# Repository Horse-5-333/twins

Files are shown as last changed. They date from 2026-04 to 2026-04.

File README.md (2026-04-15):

# Hourglass Twins Keyboard
### in 2021, [9% of Americans](https://doi.org/10.15620/cdc:129848) (~30 million people) experienced a repetitive strain injury
Constant typing in an office setting was found to be a significant risk factor. A key reason why is the keyboards many officeworkers use - the standard 104 key ANSI layout was not designed with people in mind. This project aims to implement strategic, ergonomic design choices that improve comfort during typing and decrease the risk of repetitive strain injury.
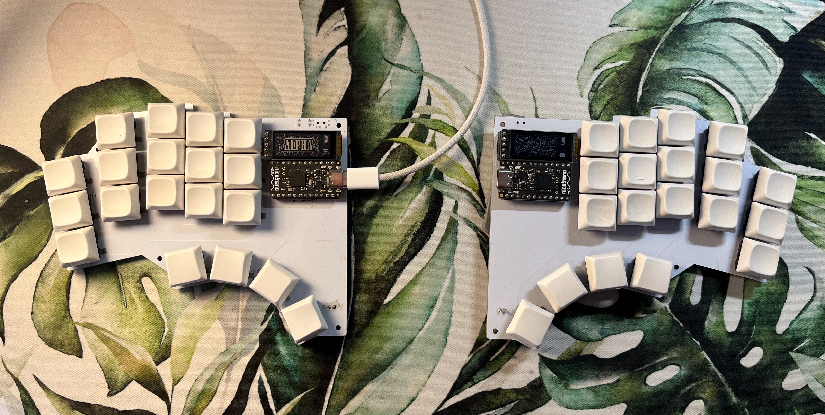
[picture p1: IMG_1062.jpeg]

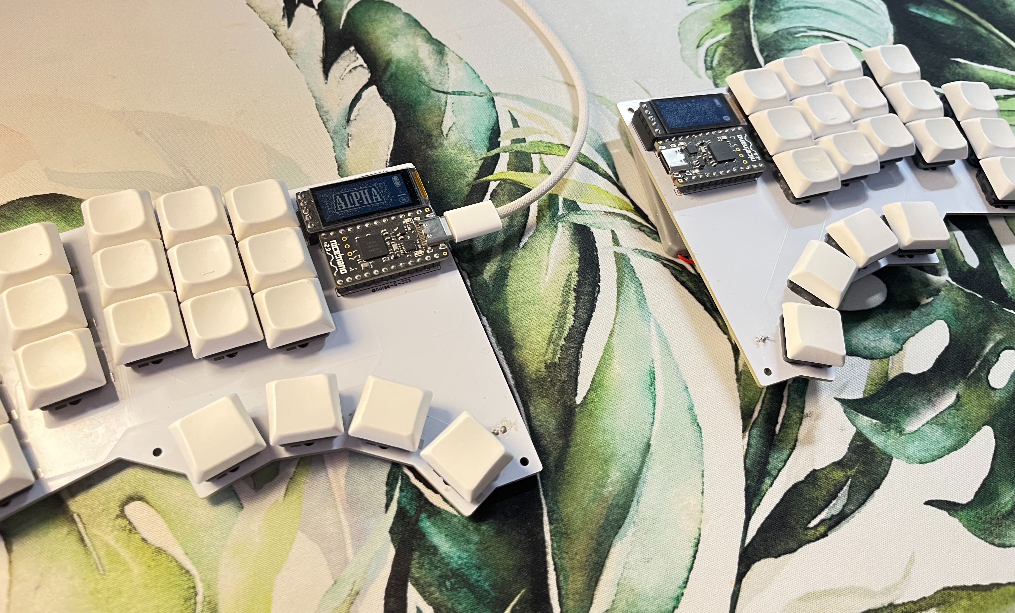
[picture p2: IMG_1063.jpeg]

## Ergonomics
The Hourglass Twins Keyboard implments, among others, 3 key design choices - a column (rather than the standard row) stagger, a thumb cluster, and angled offsets measured specifically to the average male hand size. However, this design is not without compromise; the slim layout would be a dealbreaker for many, as this keyboard only has 38 keys (though through the use of layers, there are actually 38x3=114 effective keys). The main goal of the keyboard is to unite the design and layout of the keys to the physical shape of the human hand, in positions that are comfortable to hold.

A key design goal of this keyboard was that no finger should have to move more than 1 key away to access the keys assigned to it. This, combined with the limted range of motion of the pink restricts the four main fingers to only 15 keys (the index finger gets 2 dedicated columns). The thumbs of each hand get 4 keys because it can swing wide, leading to an overall design of 19 keys per hand, or 38 total.
### Column Stagger
Typical keyboards have their rows offset from eachother. Some claim this is a vestige of typewriter design, but that source is not entirely accurate. This project uses a column stagger, where columns have different heights. This is because our finger lengths naturally vary, and it doesn't make sense to place the home row for the pinky at the same level for the middle finger.
### Angled Column Offset
Try extending your hand from a fist to palm-flat - notice how your fingers _aren't_ parallel? Even many ergonomic keyboards like to assume they are, but this one doesn't. The pinky and ring finger columns both angle away from the central cluster because that's how those fingers look on a hand. Pressing a top key with the pinky is far more comfortable if it just has to extend along its own axis.
### Thumb Cluster
The ANSI layout reserves almost 20% of the hand's fingers for one key: the spacebar. The thumb rarely presses  anything else on a standard keyboard. So, this keyboard utilizes the thumbs extensive range of motion with a comfortable thumb cluster positioned at the center of the board.

## Design
### Layers
Though noted in the paper that Dvorak should be used, further research into the topic reveals there are significantly more advancements to be made. This repo can be forked and the config file edited to match a more standard layout if desired.

The current layer is noted on the e-ink display on the left-half board.
| Layer | Access Key |  Mode | Details |
| -- | -- | -- | -- |
| Alpha | None | Default | Currently using a modified version of the [Caster Layout](https://cyanophage.github.io/#caster). |
| Symbol | Leftmost thumbkey of right-cluster | Hold | Alpha keys are overwritten with symbols such as !@#$%^&*() |
| Number | Rightmost thumbkey of left-cluster | Hold | Alpha keys are overwritten with a numpad on the right board and nav keys on the left board |
| QWERTY (game) | Symbol + Number layer keys at the same time| Toggle | Contains a QWERTY mode on the left-half, with an arragement o `F` keys on the right half. The configuration layer can be accessed from here |
| Config | Rightmost thumbkey of right-cluster while in QWERTY layer | Toggle | This layer contains keys that can control the Bluetooth connections of the board, and reset the board entirely |

### PCB Creation
Initially, I started with a design that I fine-tuned to match my hand from [ergogen](https://ergogen.cache.works/), a website specifically created to help improve the process of creating an ergonomic keyboard. I wrote a YAML configuration file, including PCB schematics and 3d printable bases, and exported it for use in KiCad and Fusion360. From there, I iterated over the design in KiCad, routing the hotswap sockets ergogen placed in the file to a microcontroller footprint on the main board. However, after ordering through JLCPCB, I learned there was a routing error in the drill file - a path overlapped a hotswap footprint where it should not, making a key that thought it was _always depressed_. This forced me to be more careful with my DRC before printing, though I am surprised I didn't catch this.

### Choosing a Layout
Initially, I was going to use Dvorak because it was the name that had popped up most in the academic research space on keyboard layouts. However, beyond that, in the online space, people have take what Dvorak has done and applied further optimization of keyboard layouts. As I had already decided this keyboard would use a custom layout which would require a strict learning curve anyways, I decided to go with what has been settled upon as the design with the least typing effort - that is, a layout chosen strictly for its ability to maximze rolls and alternations while reducing scissors. Each of these are specific phenomena that occur when typing, based on the most common english bigrams (sequences of 2 letters). The layout I choose, a modified [caster](https://cyanophage.github.io/#caster), is unique in that it places `e` on the thumb cluster. Most layouts avoid this simply because the thumb cluster is typically reserved for modifier and layer keys, but this is only because it is traditional.
## Building It Yourself
### Bill of Materials
| Component | Count | Details | Source | Cost | 
| -- | -- | -- | -- | -- |
| Hourglass Twins L/R PCB Pair | 1x | Gerber and Drill files can be found in this repository. Min order size through JLCPCB is 5x each half (kinda wasteful, I'm looking into a reversible design) | JCLPCB | $35 |
| nice!nanoV2 | 2x | Supports wireless capabilities and QMK | [typeractive.xyz](https://typeractive.xyz/products/nice-nano) | $50 |
| Kalih Choc LP Ambients Twilight | 32x | Regarded as one of the highest quality low profile switches with an exceptionally silent operation and light force of 35gf | [lowprokb.ca](https://lowprokb.ca/products/ambients-silent-choc-switches) | $36 |
| Kalih Choc LP Ambients Nocturnal | 6x | Used on the pinky keys with an even lighter operation force of 20gf | [lowprokb.ca](https://lowprokb.ca/products/ambients-silent-choc-switches) | $9 |
| LDSA LP Keycaps | 28x | Used for most keycaps | [lowprokb.ca](https://lowprokb.ca/collections/keycaps/products/ldsa-low-profile-blank-keycaps) | $10.50 |
| LDSA LP Homing Bar Keycaps | 2x | Used on this board's equivalent "home row," where the pointer fingers are meant to rest | [lowprokb.ca](https://lowprokb.ca/collections/keycaps/products/ldsa-low-profile-blank-keycaps) | $1 |
| LDSA LP Convex Keycaps | 8x | Used on the thumb cluster, as concave kecaps here would be hard to navigate smoothly | [lowprokb.ca](https://lowprokb.ca/collections/keycaps/products/ldsa-low-profile-blank-keycaps) | $3 |
| Kalih Choc Hotswap Sockets | 38x | Allows for future customization of keycaps if desired | [lowprokb.ca](https://lowprokb.ca/collections/keycaps/products/ldsa-low-profile-blank-keycaps) | $7 |
| SMD Diodes | 38x | Prevents ghost keys and allows matrix-scanning algorithm to function properly | [typeractive.xyz](https://typeractive.xyz/products/smd-diodes) | $3 |
| nice!view | 2x | Low power e-ink display to view layer, battery life, connected device (only 1 is neccesary on left half, but I used 2 for symmetry's sake) | [typeractive.xyz](https://typeractive.xyz/products/nice-view) | $40 |
| Reset Button | 2x | Allows to reset board to factory firmware, clearing device connections | [typeractive.xyz](https://typeractive.xyz/products/reset-button) | $1.50 |
| Power Switch | 2x | Disconnect battery from microcontroller for long term storage | [typeractive.xyz](https://typeractive.xyz/products/power-switch) | $1.50 |
| Machine Sockets + Pins | 4x12 | Used to add a swapable connection for the nice!nano to the PCB so a dead microcontroller doesn't take the device with it. Needs 4 rows of 12 sockets/pins | [typeractive.xyz](https://typeractive.xyz/products/machine-sockets-and-pins) | $13 |
| 1800 mAh LIP1359 Battery Pack | 2x | Exceptionally large battery for keyboard use, with this setup can see ~6 months of battery life with consistent usage | [amazon.ca](https://www.amazon.ca/Pickle-Power-Controller-PlayStation-Dualshock/dp/B0FYLYFLW2) | $14 |
| | | | Total Cost: | $224.50 |

## Installation
_zmk for the nice!nanoV2_

This repository hosts the necessary shields and boards for Horse-5-333's Hourglass Twins keyboard. 

Updated firmware can be found under the `Actions` tab, where each workflow contains an `firmware.zip` file containing 3 `.uf2` firmware files. Each half of the board is flashed individually by rapidly clicking the reset button until the LED on the nice!nano pulses blue. Plugging one half at this time will mount it as a mass storage device labeled `NICENANO`. Move the respective `.uf2` file (ie, `twins_left twins_view_adapter nice_view_elemental-nice_nano_v2-zmk.uf2` for the left half board) into this drive. Once file transfer is complete, the keyboard should automatically eject itself from the computer.
### The Reset Firmware
`settings_reset-nice_nano_v2-zmk.uf2` is a file in the more recent firmware packages that will clear all onboard memory on the nice!nano. This is useful to reset the bluetooth connection while testing and just factory resetting the nice!nano in case something goes wrong.

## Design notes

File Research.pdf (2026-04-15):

1

An Introduction to the Function of Computer Keyboards and the Application of Ergonomics to their Design

K.G.

February 20, 2025

APPLICATION OF ERGONOMICS IN KEYBOARDS | 2

The keyboards on phones, computers, and laptops have not changed significantly since Christopher Sholes patented their layout in 1878. Those earliest keyboards, designed for the Type-Writer, were severely limited by mechanical constraints and had little room to prioritize operator health and comfort, the principles of ergonomic design. However, the oversight of these principles is not without risk; in 2021, 9% of Americans reported experiencing a repetitive strain injury (RSI) in the past three months (Garnett et al., 2023), a condition prevalent among office workers and typists working in poor ergonomic environments.
Although modern designs can innovate on the stiff rigidity of the early Type-Writer, few do. Ergonomically focused keyboards seem to discourage consumers who have experience with the traditional 104 switch keyboard (American National Standards Institute, 1988). Despite their lack of popularity, ergonomic keyboards create superior typing experiences compared to the standard keyboard. Specifically, the usage of ergonomic components assembled with anatomical limitations in mind - rather than mechanical - improves user experience and health. Implementation of the Computer Keyboard

The basic computer keyboard is comprised of four parts: a circuit board, a microprocessor, switches, and the computer interface.
A circuit board is a lamination of an insulating substrate between thin sheets of copper foil. Components are soldered to the lines etched in the foil, electrically bridging them and completing the circuit. For keyboards, the circuit board is arranged in grid of copper lines. Each horizontal line connects a row of switches, while each vertical line connects a column. This grid is connected to the input and output (I/O) pins of the microprocessor (Keim, 2020). The circuit board controls where switches can be placed, informing the physical layout of the keyboard. Although staggered rows are standard, a perfect grid or even staggered columns may show ergonomic improvements by matching finger travel with finger length. For example, the middle finger is longer than the pinky, so it can travel farther without straining the hands.
There are three major actuation systems found in keyboards: mechanical switches (not to be confused with the mechanical systems of the Type-Writer), membrane/dome contacts, and scissor switches. However, of the three actuation methods, only mechanical keyboards use individual switches. Membrane/dome contacts use printed rubber sheets across a flat board, and optional interlocking stabilizers typify scissor switches. For mechanical switches, each switch is soldered individually to the circuit board. When depressed, the switch connects the copper lines beneath, completing the circuit. The microprocessor uses the completed circuit to detect a key input. The actuation force, the typing feedback, and the travel distance of the key are all informed by the switch used. Ergonomically, low-force switches that provide physical feedback (sound or feel) are best (Hargreaves et al., 1992). Shorter switches are typically better than taller ones as they reduce the overall height of the keyboard, in turn reducing wrist extension.
The microprocessor detects input on the circuit board and converts those signals to computer-readable key codes. To achieve this, the microprocessor sends a signal along each copper row in sequence. Then, the voltage on every input pin is measured. If a switch is depressed, the voltage from the output pin travels through the row line, through the switch, finally exiting to the column line and into the input pin (see Figure 1). The row and columns with matching voltages are therefore connected (Boone, 2021). The locations of the active column and row are checked against a lookup table that stores the corresponding key code (Vears, 1990). The microprocessor sends the value stored in that table to the computer through the interface system. Keyboards communicate with the computer along the shared interface, usually Universal Serial Bus (USB). During usage, the device functions in interrupt mode, meaning the host queries the device at a device-set polling rate, requesting an update to the device’s state (Conor, n.d.). The device then responds with an Interrupt Report if a change has been made, i.e. a new key is pressed or a previously pressed key was lifted. Although the interface and microprocessor have less bearing on user comfort, microprocessors with wireless capabilities can increase the portability of the keyboard, allowing users to work from more comfortable positions.
Ergonomic Implications of Design Choices

Although the main purpose of the keyboard is to type, they often perform many alternate tasks. Modifier keys, like Control and Alternate, are used in conjunction with the alphanumeric

Figure 1
A Simplified Hex Input Keypad

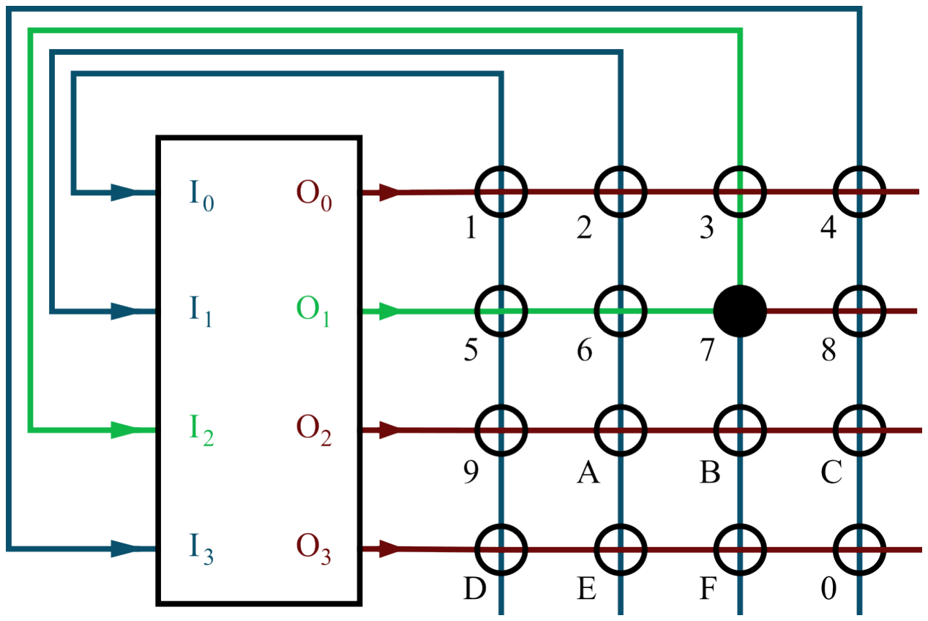
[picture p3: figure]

Note. The microprocessor scans output pin O1 and current flows through a switch to input pin I2. The microprocessor finds character code 7 is associated with O1 and I2.

keys to directly control computer behavior outside typing. These non-typing keys are present on every modern keyboard. Despite their ubiquitous presence, though, not every special key is useful for every system. Take the navigation keys: the arrow keys, insert, home, page up, delete, insert, and page down. Before computer mouses, the keyboard was the only method of input to a home computer, and additional keys were necessary to navigate the computer. Then, Apple’s Macintosh popularized the computer mouse in 1984 (Burnham, 1984), and many manufacturers followed suit. Computer programs now expect a mouse or other pointing device, even beyond basic support. The mouse has largely replaced the need for the navigation keys. Despite this, most keyboard manufacturers retain the cluster on their keyboards - most likely to comply with keyboard layout standards set by the American National Standards Institute in 1988.
Some users with disability or accessibility requirements may rely exclusively on these keys to use modern programs. However, for the majority of consumers, the navigation cluster is rarely used. Removing these keys may aid ergonomics by simplifying the layout and reducing finger travel. According to Hargreaves et al. (1992), "Dynamic work performed during keyboard use primarily involves the small muscles of the fingers. Design parameters that affect this effort are key travel, key shape, inter-key distance, keying frequency, keyboard shape, and key assignment (layout)." Reducing the effort necessary to use the keyboard improves the user’s experience and increases comfort during use. Layouts have been designed by purposefully applying these parameters to benefit ergonomics. The Dvorak layout was designed specifically to reduce finger travel by placing commonly used key pairs near each other, and maintaining the most common keys on the home row. Torres’ (2013) computation approach measured "additional effort associated with a displacement of the hand. For intermediate values of this parameter, the gain in efficiency exceeds 10%." Fortunately, far more significant changes are seen when altering the base design of the keyboard.
Most modern keyboards are shaped as a shallow rectangular wedge placed on the largest face. Unfortunately, this design often forces users into unnatural, uncomfortable positions. The far rows of keys are elevated above the closer ones, forcing the user’s wrists to extend vertically. Also, the placement of the hands on the home row is far closer than the shoulders of the user, forcing the arms to angle inwards and the wrists to deviate ulnarly (away from the body’s centerline) to compensate. Finally, placing hands flat on the typing surface (pronated) does not match the natural position of the hands resting vertically on the pinky. These maintained positions of strain and unnecessary tension can significantly impact the health of the user (Marcaccio, 2024). Wrist extension is a major risk factor in the development of carpal tunnel syndrome, the most common repetitive strain injury. When the carpals (wrists) are extended to reach the far, elevated keys of a standard keyboard, the median nerve can be compressed (Genova et al., 2020). Repetitive strain injuries "can result in several health consequences including pain, numbness, and a limitation or loss of mobility" (Garnett et al., 2023). In that report, Garnett et al. (2023) found 9% of Americans reported a repetitive strain injury at least once in a 3-month period in 2021. 44.2% of those affected limited their activities as a result of the injury. Although conservative treatments for carpal tunnel are effective - an approximately 80% positive response rate -symptoms return to roughly 80% of those with a positive response to treatment within a year. Drastic changes to the keyboards are necessary to reduce these symptoms. Hargreaves et al. (1992) found "three styles predominate: articulated traditional keyboards, chording keyboards, and hand-contoured keyboards." Articulated keyboards contain a hinge or join along the middle column of keys to create an angle between the halves. Chording keyboards, quite similar to stenography, have few keys and are used more similarly to a piano, where combinations of keys (chords) produce syllables and phonetic approximations to accelerate typing (Marsha, 2024). Hand-contoured keyboards use spherical wells for each hand to match the shape of the hands. These three designs seek the same result: reduced strain, improved posture, and minimized forces. Specifically, articulated and hand-contoured keyboards achieve this through their geometry. On hand-contoured keyboards, Hargreaves et al. (1992) states their "overall geometry reduces pronation, ulnar deviation, wrist extension, and little finger abduction," which are all significant risk factors for repetitive strain injuries. Although hand-contoured keyboards better match the shape of the hands and digits, articulated keyboards retain 3 select advantages over them: (a) articulated keyboards have shorter vertical profiles and may have a negative slant, reducing wrist extension; (b) their flat profiles are significantly easier to manufacture; and (c) the split between the halves is adjustable to the specific needs of the user. "Adjustability is absolutely essential, since we have a broad age span of workers and a broad anthropometric variation among workers who may have very tiny hands or very large hands" (Hargreaves et al., 1992). For a broad consumer base, split keyboards are probably the best option. They significantly improve ergonomics without needing drastic manufacturing change.
The Application of Ergonomics to a Specific Use Case

The first step to producing a keyboard is identifying the use case and design goals. A keyboard designed for gaming requires increased polling rates and increased switch feedback, while a keyboard designed for office use doesn’t require a high polling rate and may even want reduced switch feedback, to reduce noise. The ergonomic keyboard to be designed here should meet three overarching goals: programming-language compatibility, portability, and adjustability. Next, these goals are implemented through specific design decisions. The Kalih Choc Twilight switch is used here as a dampened, low-profile switch so the keyboard can be easily taken anywhere and used quietly. Choc switches are smaller in all axes, reducing finger travel. Hot-swap sockets are added to the PCB to allow potential future revisions. A nice!nano V2.0 wireless microprocessor aids portability and compatibility. The PCB/key layout is the most complex choice of the ergonomic keyboard. Adherence to the ANSI standard is simple but does not effectively meet the ergonomic goal. Here, the keyboard layout generator Ergogen was used. A column-staggered, split, trimmed Dvorak layout was made to allow adjustability between halves. The Dvorak layout was taken and modified to remove unnecessary keys and move lesser-used keys to the function layer. Although characters such as the curly braces and semicolon are rarely used, they were kept in accessible positions due to their presence in programming languages. An arced cluster was added in place of the wide space bar to utilize the thumb naturally; the space input "_" was moved to a standard width key. The angles between each column was measured to match the interphalangeal angle between each finger to adhere perfectly to the natural finger positions.
This keyboard serves as a far more comfortable alternative to the laptop keyboard without utilizing much more space. Quiet switches and dampened sound through case foam make the keyboard especially useful to students studying in libraries and during lecture. Unfortunately, the modified Dvorak layout increases the learning curve for users already accustomed to QWERTY. As well, the distances and angles between columns are based on a single sample. Although the angle between halves is adjustable, the overall design of the keyboard is quite specific to a single user, reducing its appeal to more general audiences. However, for the user in mind, this keyboard significantly aids comfort and ergonomics during computer use.
Conclusion

Keyboards, along with pointing devices, determine how consumers interact with their computers. Creating a keyboard that meets the needs of enough users while maintaining economic viability is a delicate task. So, most manufacturers produce simple, recognizable full-size QWERTY keyboards. Unfortunately, this is a poor standard and a vestige of century-old technology. The standard keyboard can cause significant and permanent harm to the user through repetitive strain injury, a complication significant enough to prevent activity and reduce productivity. Billions of keyboard users would benefit from keyboards designed more for the health and comfort of the user, rather than conformity to an arbitrary design. The ergonomic keyboard fulfills this purpose. By implementing changes to the major keyboard components, ergonomic keyboards improve the comfort and health of the user. These keyboards use human anatomy and mechanics as a baseline, as maintaining natural posture reduces strain and effort when compared to stiff or awkward positions. However, these keyboards are more difficult to produce for a wide audience due to the wide variation in anatomy between individuals and needs between demographics. The best choice is a product tailored to the unique user, which makes their experience more comfortable and reduces their risk of injury from keyboard use.

References

American National Standards Institute. (1988). Office Machines and Supplies - Alphanumeric Machines - Keyboard Arragement INCITS 154-1988 [S2009]. https://webstore.ansi.org/standards/incits/incits1541988s2009
Boone, K. (2021, January). Building and Programming a USB Keypad from the Ground Up. https://kevinboone.me/pro-micro-key-test-1.html
Burnham, D. (1984). The Computer, The Consumer and Privacy. The New York Times, 8. https://www.nytimes.com/1984/03/04/weekinreview/the-computer-the-consumer-and-privacy.html (https://www.nytimes.com/1984/03/04/weekinreview/the-computer-the-consumer-and-privacy.html)
Conor, T. (n.d.). How do USB Keyboards Work? Retrieved February 5, 2025, from http://threeboard.dev/documentation/threeboard/how_usb_keyboards_work.html Garnett, M. F., Elgaddal, N., & Spencer, M. R. (2023). Repetitive Strain Injuries in Adults in the Past 3 Months: United States, 2021. National Health Statistics Reports, (189), 1–10. https://doi.org/10.15620/cdc:129848
Genova, A., Dix, O., Saefan, A., Thakur, M., & Hassan, A. (2020). Carpal Tunnel Syndrome: A Review of Literature. Cureus, 12(3), e7333. https://doi.org/10.7759/cureus.7333 Hargreaves, W., Rempel, D., Halpern, N., Markison, R., Kroemer, K., Ing, & Litewka, J. (1992). Toward a more humane keyboard. Proceedings of the SIGCHI conference on Human factors in computing systems - CHI ’92, 365–368. https://doi.org/10.1145/142750.142832 Keim, R. (2020, April). What Is a Printed Circuit Board (PCB)? https://www.allaboutcircuits.com/technical-articles/what-is-a-printed-circuit-board-pcb/Marcaccio, S. (2024, November). Repetitive Strain Injury: Types, Causes and How to Treat Them. https://www.brownhealth.org/be-well/repetitive-strain-injury-types-causes-and-how-treat-them (https://www.brownhealth.org/be-well/repetitive-strain-injury-types-causes-and-how-treat-them)
Marsha, N. (2024, March). What Is a Stenographer? Everything You Have Wondered About Shorthand Typists. https://www.naegeliusa.com/blog/what-is-a-stenographer

Sholes, C. (1878, August). Improvement in Type-Writing Machines (207559A). https://patents.google.com/patent/US207559A
Torres, R. (2013). Qwerty vs . Dvorak Efficiency: A Computational Approach. https://api.semanticscholar.org/CorpusID:26820338
Vears, R. E. (1990). Microprocessor interfacing. Heinemann Newnes. https://shop.elsevier.com/books/microprocessor-interfacing/vears/978-0-434-92336-6

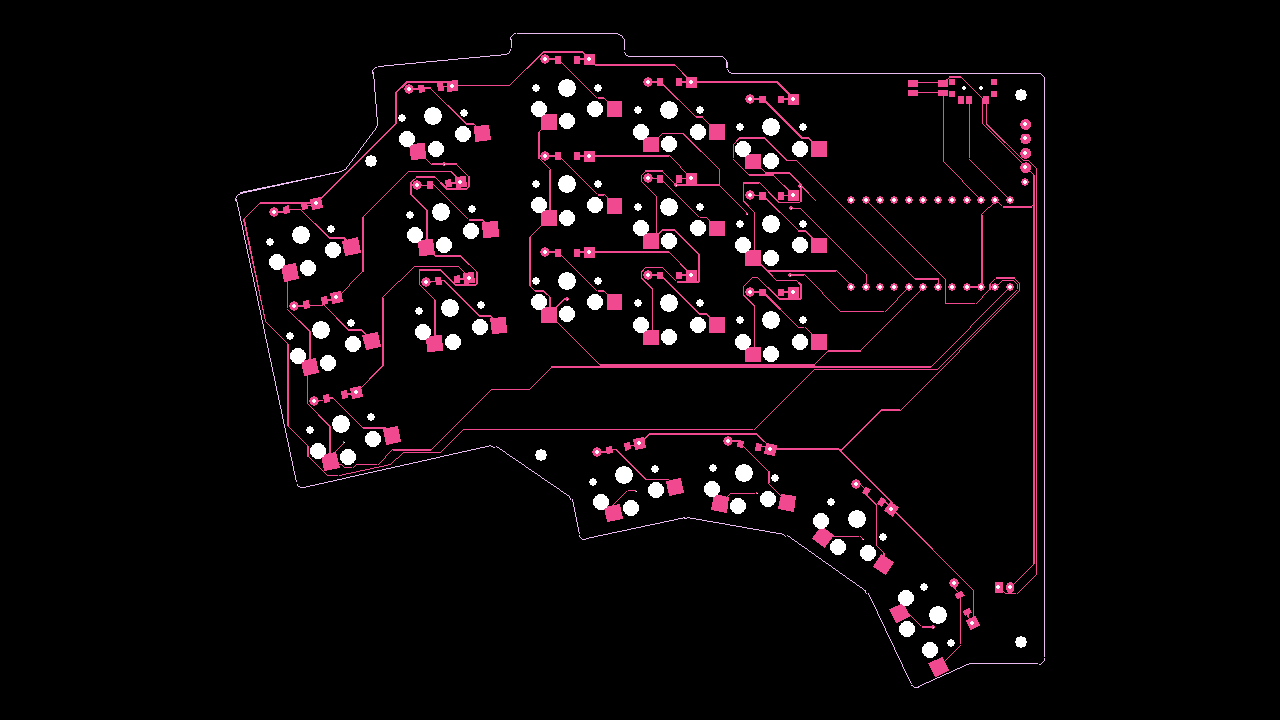
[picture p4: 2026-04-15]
gerber-drill/twins-right/yg/GBR_9028322_1_snapshot.png

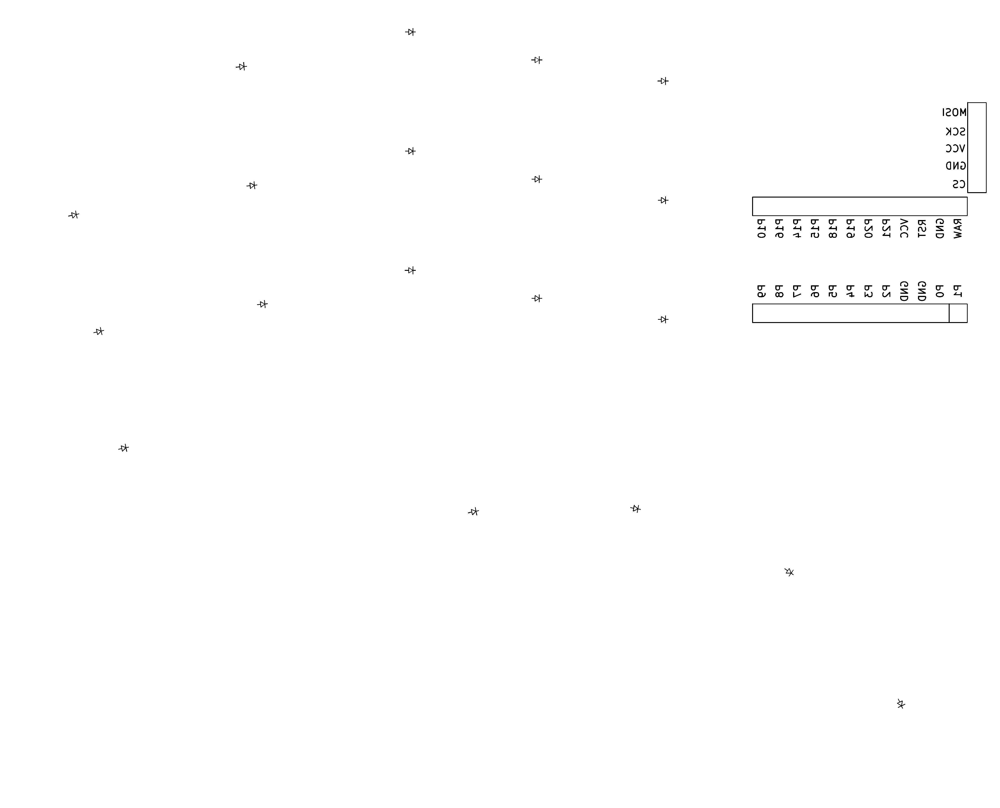
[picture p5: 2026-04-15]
gerber-drill/twins-right/yg/GBR_9028322_1_bottom.png

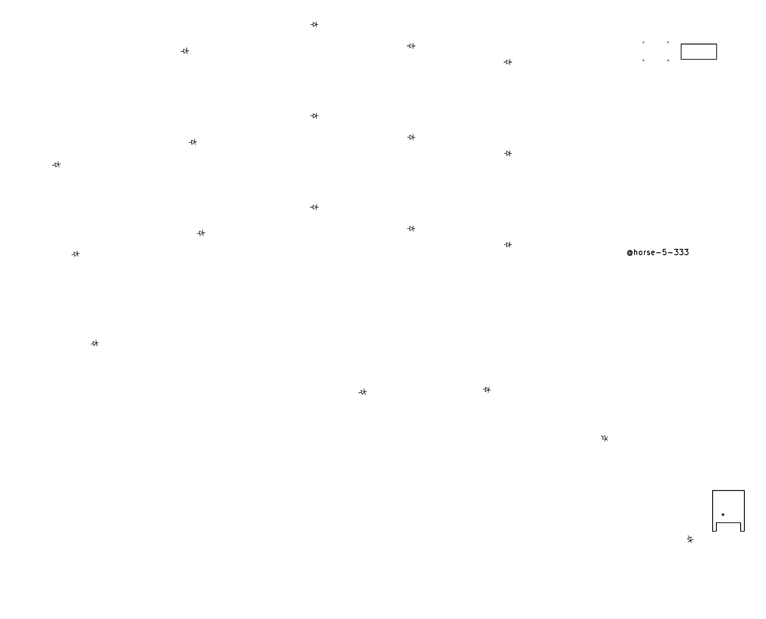
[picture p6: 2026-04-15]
gerber-drill/twins-right/yg/GBR_9028322_1_top.png

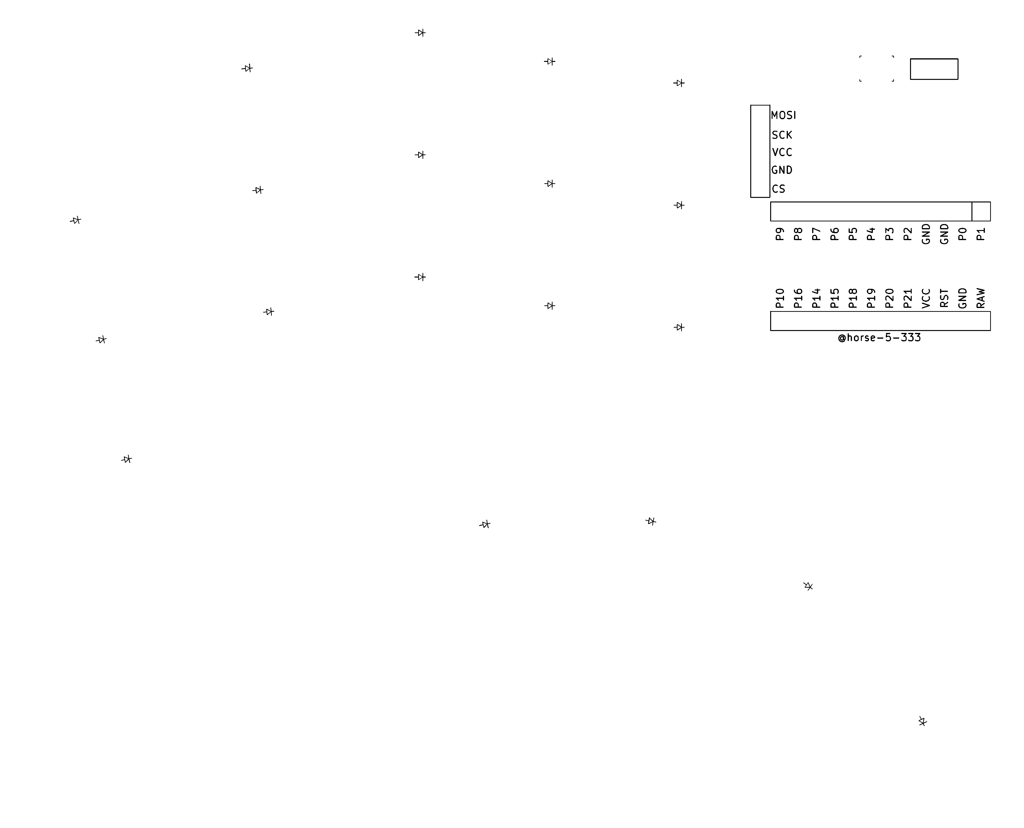
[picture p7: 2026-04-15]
gerber-drill/twins-left/yg/GBR_8921560_1_top.png

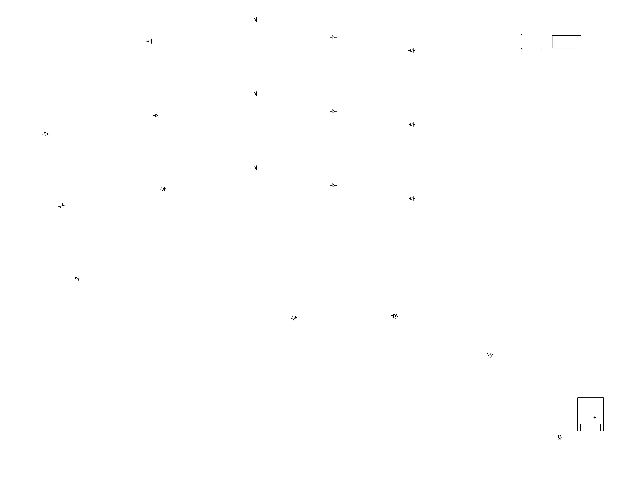
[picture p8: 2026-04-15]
gerber-drill/twins-left/yg/GBR_8921560_1_bottom.png

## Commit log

2025-03-30 customized pins to match Twin board
2025-04-22 uppdated for new pcb
